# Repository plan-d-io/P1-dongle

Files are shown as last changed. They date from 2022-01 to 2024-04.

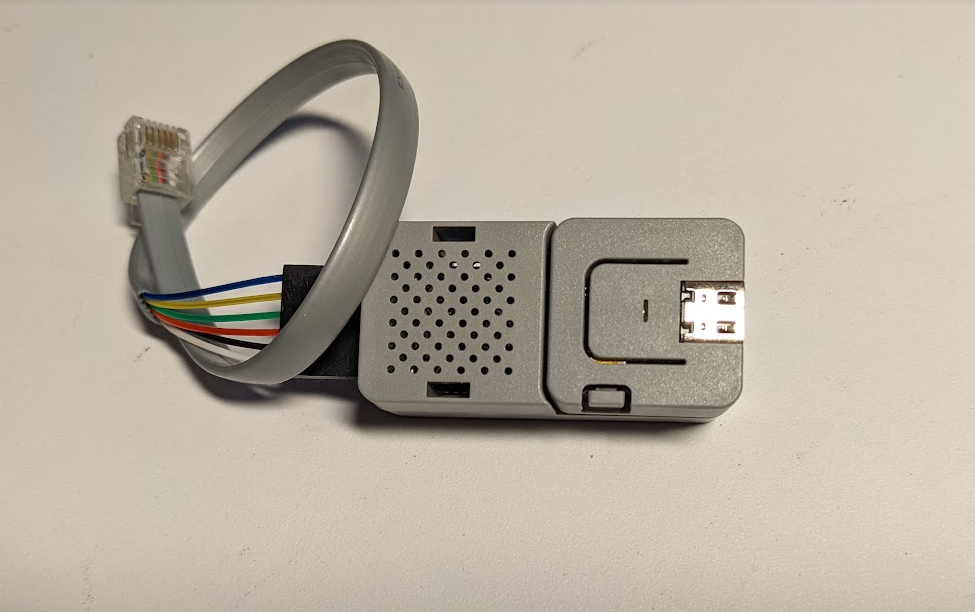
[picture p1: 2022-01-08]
hardware/P1-dongle.PNG

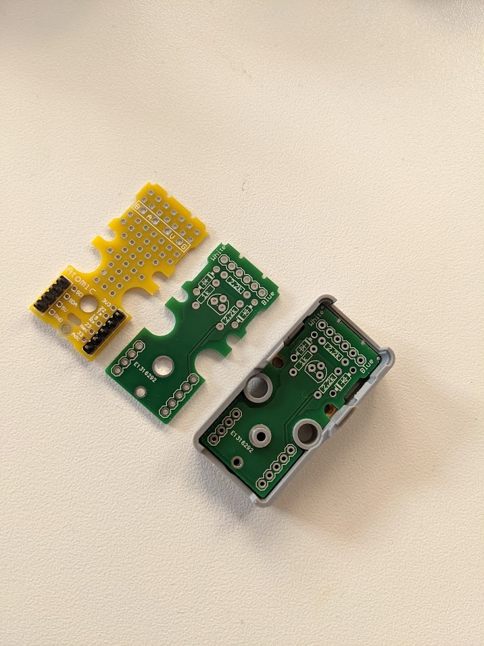
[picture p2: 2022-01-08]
hardware/P1-dongle-PCB.jpg

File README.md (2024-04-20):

# P1-dongle
ESP32-based firmware and hardware to receive, parse, store and forward energy data coming from the P1 port of Fluvius digital meters (Flanders, Belgium). Should also work on Dutch, Walloon, Luxembourg and Swedish digital meters (untested).



Please see the [wiki](https://github.com/plan-d-io/P1-dongle/wiki) for extended instructions on how to build, configure and use the P1-dongle.

## Features
- Professional looking yet easy DIY build
- Cheap (<€20 DIY cost)
- Easy to configure through web-based interface or RESTful API
- Supports MQTT, MQTT over TLS, HTTP and HTTPS data upload to local or remote servers
- Native integration into Home Assistant (MQTT autodiscovery)
- Open source firmware & hardware
- Privacy first: cloud, or even internet access entirely optional
- Auto-updating firmware (optional)
- Easy to use as a basis for other (professional) projects

I do not provide any guarantees nor timelines for developing functionality. I am however available for specific functionality or developments at request. 
And, as this is an open-source project, you are free to contribute yourself!

## Basic installation
1. Plug the P1-dongle into the P1 port of your digital meter
2. When the LED turns greens, connect to the `p1-dongle` access point
3. When connected, open the login page or go to `192.168.4.1`
4. Complete the configuration, and click the reboot button at the bottom of the webpage

# Development
- [Development roadmap](https://github.com/plan-d-io/P1-dongle/wiki/Development:-roadmap)

# Project sponsors
**Elia Innovation**



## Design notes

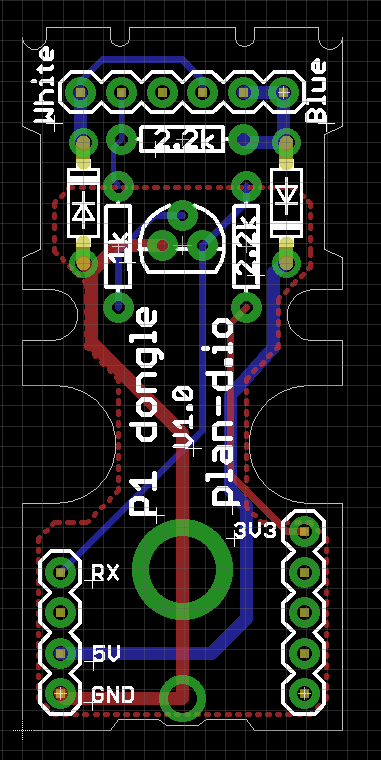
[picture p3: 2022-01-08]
hardware/P1-dongle-eagle.PNG

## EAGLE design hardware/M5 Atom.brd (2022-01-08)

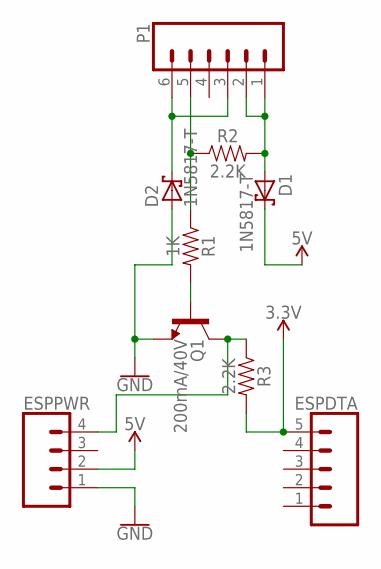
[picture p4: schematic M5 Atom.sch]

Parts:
D1, D2: 1N5817-T; DO41-7.6
ESPDTA: CONN_05; 1X05
ESPPWR: CONN_04PTH; 1X04
P1: CONN_06SILK_FEMALE_PTH; 1X06
Q1: 200mA/40V; TO-92
R1: 1K; AXIAL-0.3
R2, R3: 2.2K; AXIAL-0.3

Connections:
3.3V: ESPDTA.5, R3.P$2 (2)
5V: D1.C, ESPPWR.2
5VH: D1.A, P1.1, P1.2, R2.P$2 (2)
GND: D2.A, ESPPWR.1, Q1.1 (E)
GNDH: D2.C, P1.3, P1.6
unnamed: Q1.2 (B), R1.P$2 (2)
TXH: P1.5, R1.P$1 (1), R2.P$1 (1)
TXL: ESPPWR.4, Q1.3 (C), R3.P$1 (1)

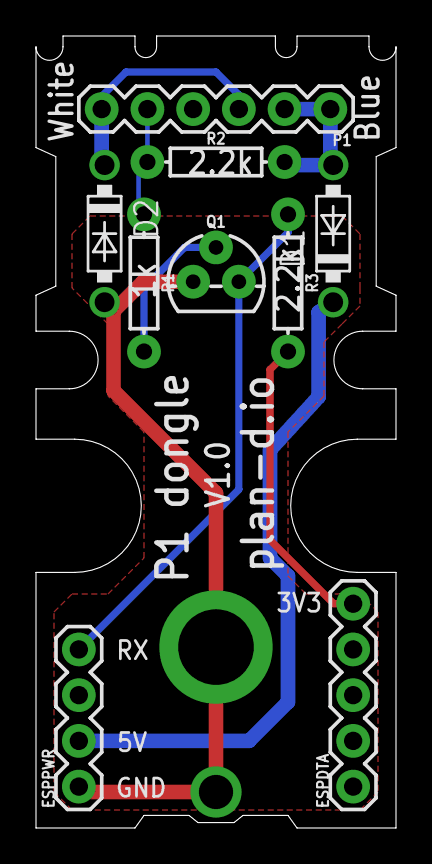
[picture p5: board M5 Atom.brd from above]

Board: 2 copper layers, 20.0 x 44.0 mm, 9 parts (0 on the bottom side), 8 nets.

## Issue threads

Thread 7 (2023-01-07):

Support for WPA2 Enterprise EAP-TTLS

mcuelenaere, 2023-01-07:
I noticed [in the code](https://github.com/plan-d-io/P1-dongle/blob/main/P1-dongle.ino#L180) that currently only WPA/WPA2 Personal support is available.

Having support for WPA2 Enterprise EAP-TTLS would be really useful for certain usecases (read as: [support Telenet Wi-Free](https://www2.telenet.be/nl/klantenservice/wat-is-telenet-wi-free/)).

Based on some quick searching through the ESP32 code, this seems to be [a supported usecase](https://github.com/espressif/arduino-esp32/blob/master/libraries/WiFiClientSecure/examples/WiFiClientSecureEnterprise/WiFiClientSecureEnterprise.ino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) and not too difficult to add support for.

I might look into adding support myself, if I get my hands on a dongle. If not, this issue can be used by someone else as a starting point to implement it.

Epyon01P, 2023-11-20:
I have not identified a clear use case for this, especially now WiF-Free is being shut down. If your digital meter is outside wifi coverage, perhaps you can take a look at my [LoRa dongle](https://github.com/plan-d-io/P1-LoRa-receiver).

Closed 2023-11-20.

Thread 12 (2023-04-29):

Upload to InfluxDB (feature request)

michaelpiron, 2023-04-29:
Feature request:
It would be great if the P1-dongle is able to push measurements directly towards an Influx DB.

Example for inspiration:
IotaWatt energy monitor (ESP-based) is able to upload data to an InfluxDB (version 1 & version 2).
--> https://docs.iotawatt.com/en/master/influxDB.html

UI allows to configure:
* post interval
* bulk send (how many samples are aggregated into one HTTP request)
* server URL
* tags

Code opensource on Github:
* https://github.com/boblemaire/IoTaWatt/blob/master/Firmware/IotaWatt/influxDB_v1_uploader.cpp
* https://github.com/boblemaire/IoTaWatt/blob/master/Firmware/IotaWatt/influxDB_v2_uploader.cpp

Epyon01P, 2023-06-07:
Good suggestion. Currently the dongle has no data buffer, so only a direct push to Influx would be possible. A buffer is on the roadmap, so I'll add this feature afterwards.

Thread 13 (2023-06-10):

add "state_class": "total_increasing", to T1 and T2

koenkv, 2023-06-10:
can you add the "state_class": "total_increasing", to the mqtt message for homeassistant/sensor/utility_meter_total_consumption_t1 and homeassistant/sensor/utility_meter_total_consumption_t2

Epyon01P, 2023-11-23:
Fixed in version 2.10

Closed 2023-11-23.

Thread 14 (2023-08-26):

Discovered entities with a name that starts with the device name

waaslandwolf, 2023-08-26:
Since doing an upgrade, I receive the following warning in Home Assistant for the P1 dongle device:

Discovered entities with a name that starts with the device name

This stops working in version 2024.2.0. Please address before upgrading.

Some MQTT entities have an entity name that starts with the device name. This is not expected. To avoid a duplicate name the device name prefix is stripped off the entity name as a work-a-round. Please inform the maintainer of the software application that supplies the affected entities to fix this issue.

List of affected entities:

    sensor.p197af50_reboots
    sensor.utility_meter_total_consumption_t2
    sensor.p197af50_free_heap_size
    sensor.p197af50_min_free_heap
    sensor.cofyaf50_firmware
    sensor.utility_meter_voltage_phase_2
    sensor.utility_meter_total_consumption_t1
    sensor.cofyaf50_last_reset_reason
    sensor.utility_meter_current_phase_1
    sensor.cofyaf50_syslog
    sensor.utility_meter_active_power_consumption
    sensor.utility_meter_text_message
    sensor.cofyaf50_reboots
    sensor.cofyaf50_min_free_heap
    sensor.utility_meter_maximum_demand_current_month
    sensor.p197af50_ip
    sensor.cofyaf50_free_heap_size
    sensor.utility_meter_total_active_power
    sensor.p197af50_last_reset_reason
    sensor.cofyaf50_max_allocatable_block
    sensor.utility_meter_voltage_phase_1
    sensor.utility_meter_natural_gas_consumption
    sensor.p197af50_max_allocatable_block
    sensor.p197af50_last_reset_reason_verbose
    switch.p197af50_reboot
    sensor.cofyaf50_last_reset_reason_verbose
    sensor.utility_meter_current_average_demand
    sensor.p197af50_syslog
    sensor.utility_meter_total_energy_injected
    sensor.utility_meter_current_phase_3
    sensor.p197af50_firmware
    sensor.utility_meter_total_injection_t2
    sensor.utility_meter_active_power_injection
    sensor.cofyaf50_ip
    sensor.utility_meter_active_tariff_period
    sensor.utility_meter_total_injection_t1
    sensor.utility_meter_current_phase_2
    sensor.utility_meter_voltage_phase_3
    switch.cofyaf50_reboot
    sensor.utility_meter_total_energy_consumed

Home Assistant: Installed version 2023.8.3
P1 Dongle: INFO: Digital meter dongle COFYAF50 V1.08 by plan-d.io

Epyon01P, 2023-11-20:
Fixed with version 2.x

Closed 2023-11-20.

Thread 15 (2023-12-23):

Spiking/dropping sensor values in HA

michaelpiron, 2023-12-23:
Every now and then, sensor values from the P1 dongle have spikes in Home Assistant.

Example: Utility meter Maximum demand current month:
Peak value of over 2.000.000.000 kW:
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

This also happens with sensor Utility meter total energy consumed:
The example below shows a short but deep drop in the normally increasing value, which blows up the whole energy cost calculation:
Drop in total energy consumed:
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

Resulting energy cost calculation:
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

Firmware version 2.10:
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

More debug info:
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

Epyon01P, 2023-12-24:
Coincidentally, I noticed the same behaviour this week too. I have implemented a fix and pushed it to the develop branch. If you switch the release channel (under Dongle setttings in the webmin) you will fetch the latest version (v2.17). Your dongle will reboot multiple times, as I also switched to a new TLS certificate bundle. There is [one breaking change](https://github.com/plan-d-io/P1-dongle/releases/tag/V2.15), but it only concerns the EnergieID integration.

I will push it to the main channel next week.

michaelpiron, 2024-01-09:
I deployed the new version on my dongle, things were running correctly for days, however today I got this:
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

Epyon01P, 2024-01-10:
Implemented test fix in v2.19 on development branch.

michaelpiron, 2024-01-18:
I still have issues:
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

Issue started 15-Jan at noon:
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

Syslog:
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

Epyon01P, 2024-01-20:
Added extra checks in v2.20.

michaelpiron, 2024-01-22:
Issue still present in v2.2.
Today:
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

Epyon01P, 2024-01-22:
Thanks. Seeing how it is now just a erroneous reading and not an overflow anymore gave me more insight in the problem. Test fix pushed to V2.21 on develop.

jantielens, 2024-03-25:
Is this supposed to be fixed in v2.2? I'm still seeing gigantic spikes, for example here in my gas consumption.
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
(I hope these values are incorrect ;) )

Epyon01P, 2024-03-25:
Are you also on develop, or on main?

jantielens, 2024-03-26:
> Are you also on develop, or on main?

I'm on main.

Epyon01P, 2024-04-20:
Should be fixed now in V2.23.

Closed 2024-05-14.

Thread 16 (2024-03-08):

Total active power no longer updated

michaelpiron, 2024-03-08:
Since 20minutes ago, the dongle stopped publishing "total_active_power" values, whereas "active_power_consumption" & "active_power_production" continue to be updated.

MQTT log:
data > devices > utility_meter has no "total_active_power" topic anymore:
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

Sensor "active_power_injection" still being updated:
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

Sensor "total_active_power" stopped being updated:
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

michaelpiron, 2024-03-08:
A few minutes later, the "total_active_power" topic has appeared again in the MQTT log, and the HA sensor is again being updated:
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

There has been a gap for 23 minutes:
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

What could be causing this?

Epyon01P, 2024-03-16:
I believe the spurious reading detection is acting up again. Which release channel are you on? This should be fixed on the develop channel.

michaelpiron, 2024-03-17:
I’m on dev channel, and have been on version 2.22 when the issue happened:

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

jantielens, 2024-03-25:
Same here. For a couple of weeks, the "Total active power" value "gets stuck" randomly, and for some random time.
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

Epyon01P, 2024-03-25:
Thx, very helpful. This is due the way the dongle currently blanks invalid readings received from the meter. I will overhaul the whole function to also fix #15 .

Epyon01P, 2024-04-02:
Pushed a (long overdue) fix to dev. Should also fix #15 .
The issue had to do with negative values (injection) being incorrectly flagged as invalid. This slipped through my testing routine (I don't have solar panels).

Epyon01P, 2024-04-20:
Fixed in V2.23.

maxhelskens, 2024-11-06:
I am not sure if this is the same issue, but I constantly get the following syslog message:

```
WARNING: Spurious value for DSMR key 1-0:2.8.2: 0.01, 2, 1
```

The log is always about key 2.8.2.

Multiple HA entities remain unknown and the other entities do not always update.

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

I have Firmware version 2.23 installed.

Closed 2024-04-20.

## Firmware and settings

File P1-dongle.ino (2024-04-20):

#include "rom/rtc.h"
#include <esp_int_wdt.h>
#include <esp_task_wdt.h>
#include "M5Atom.h"
#include <LittleFS.h>
#define SPIFFS LittleFS
#include <WiFi.h>
#include <HTTPClient.h>
#include <WiFiClientSecure.h>
#include <DNSServer.h>
#include <ESPmDNS.h>
#include <WiFi.h>
#include <AsyncTCP.h>
#include "ESPAsyncWebServer.h"
#include <Preferences.h>
#include <PubSubClient.h>
#include <time.h>
#include <Update.h>
#include "ArduinoJson.h"
#include <elapsedMillis.h>
#include "UUID.h"
#include "configStore.h"
#include "ledControl.h"
#include "externalIntegrations.h"
#include "WebRequestHandler.h"
#include "webHelp.h"
#define HWSERIAL Serial1
#define TRIGGER 25 //Pin to trigger meter telegram request

unsigned int fw_ver = 223;

//General global vars
Preferences preferences;
AsyncWebServer server(80);
DNSServer dnsServer;
uint8_t* certData = nullptr; 
WiFiClient wificlient;
PubSubClient mqttclient(wificlient);
WiFiClientSecure *client = new WiFiClientSecure;
PubSubClient mqttclientSecure(*client);
HTTPClient https;
UUID uuid;
bool clientSecureBusy, mqttPaused, mqttWasPaused, resetWifi, factoryReset, updateAvailable;
bool wifiError, mqttWasConnected, wifiSave, wifiScan, debugInfo, timeconfigured, timeSet, spiffsMounted,rebootInit;
bool bundleLoaded = true;
bool haDiscovered = false;
String configBuffer, resetReason, infoMsg, ssidList;
char apSSID[] = "P1000000";
unsigned int mqttPushCount, mqttPushFails, onlineVersion, fw_new;
unsigned int secureClientError = 0;
time_t meterTimestamp;
//Global timing vars
elapsedMillis sinceConnCheck, sinceUpdateCheck, sinceClockCheck, sinceLastUpload, sinceDebugUpload, sinceRebootCheck, sinceMeterCheck, sinceWifiCheck, sinceTelegramRequest;
//General housekeeping vars
unsigned int reconncount, remotehostcount, telegramCount, telegramAction;
int wifiRSSI;
float freeHeap, minFreeHeap, maxAllocHeap;
byte mac[6];
uint8_t prevButtonState = false;
/*Debug*/
bool serialDebug = true;
bool telegramDebug = false;
bool mqttDebug = false;
bool httpDebug = false;
bool extendedTelegramDebug = false;

void setup(){
  M5.begin(true, false, true);
  delay(2000);
  pinMode(TRIGGER, OUTPUT);
  setBuff(0x00, 0xff, 0x00); //red 
  M5.dis.displaybuff(DisBuff);
  unitState = -1;
  Serial.begin(115200);
  HWSERIAL.begin(115200, SERIAL_8N1, 21, 22);
  delay(500);
  getHostname();
  Serial.println();
  syslog("Digital meter dongle booting", 0);
  restoreConfig();
  initSPIFFS();
  externalIntegrationsBootstrap();
  if(_trigger_type == 0) digitalWrite(TRIGGER, HIGH);
  else digitalWrite(TRIGGER, LOW);
  syslog("Digital meter dongle " + String(apSSID) +" V" + String(fw_ver/100.0) + " by plan-d.io", 1);
  if(_dev_fleet) syslog("Using experimental (development) firmware", 2); //change this to one variable, but keep legacy compatibility intact
  if(_alpha_fleet) syslog("Using pre-release (alpha) firmware", 0);
  if(_v2_fleet) syslog("Using V2.0 firmware", 0);
  syslog("Checking if internal clock is set", 0);
  printLocalTime(true);
  _bootcount = _bootcount + 1;
  syslog("Boot #" + String(_bootcount), 1);
  saveBoots();
  get_reset_reason(rtc_get_reset_reason(0));
  syslog("Last reset reason (hardware): " + resetReason, 1);
  syslog("Last reset reason (firmware): " + _last_reset, 1);
  debugInfo = true;
  initWifi();
  server.addHandler(new WebRequestHandler());
  server.begin();
  configBuffer = returnConfig();
  String availabilityTopic = _mqtt_prefix.substring(0, _mqtt_prefix.length()-1);
  Serial.println("Done");
}

void loop(){
  blinkLed();
  if(wifiScan) scanWifi();
  if(sinceRebootCheck > 2000){
    if(rebootInit){
      forcedReset();
    }
    sinceRebootCheck = 0;
  }
  if(_trigger_type == 0){
    /*Continous triggering of meter telegrams*/
    if(sinceMeterCheck > 30000){
      if(!meterError) syslog("Meter disconnected", 2);
      meterError = true;
      if(_wifi_STA && unitState < 7) unitState = 6;
      else if(!_wifi_STA && unitState < 3) unitState = 2;
      sinceMeterCheck = 0;
    }
  }
  else if(_trigger_type == 1){
    /*On demand triggering of meter telegram*/
    if(sinceTelegramRequest >= _trigger_interval *1000){
      digitalWrite(TRIGGER, HIGH);
      sinceTelegramRequest = 0;
    }
    if(sinceMeterCheck > (_trigger_interval *1000) + 30000){
      syslog("Meter disconnected", 2);
      meterError = true;
      if(_wifi_STA && unitState < 7) unitState = 6;
      else if(!_wifi_STA && unitState < 3) unitState = 2;
      sinceMeterCheck = 0;
    }
  }
  if(!_wifi_STA){
    /*If dongle is in access point mode*/
    dnsServer.processNextRequest();
    if(sinceWifiCheck >= 600000){
      /*If dongle is in AP mode, check every once in a while if the configured wifi SSID can't be detected
       * If so, reboot so the dongle starts up again in connected STA mode. */
      if(scanWifi()){
        saveResetReason("Found saved WiFi SSID, rebooting to reconnect");
        if(saveConfig()){
          syslog("Found saved WiFi SSID, rebooting to reconnect", 1);
          setReboot();
        }
      }
      sinceWifiCheck = 0;
    }
    if(sinceClockCheck >= 600000){
      timeSet = false;
      sinceClockCheck = 0;
    }
  }
  else{
    /*If dongle is connected to wifi*/
    if(!bundleLoaded) restoreSPIFFS();
    if(_mqtt_en){
      if(_mqtt_tls){
        mqttclientSecure.loop();
      }
      else{
        mqttclient.loop();
      }
    }
    if(lastEIDcheck >= EIDcheckInterval){
      eidHello();
    }
    if(lastEIDupload > EIDuploadInterval){
      eidUpload();
    }
    if(_update_autoCheck && sinceUpdateCheck >= 86400000){
      updateAvailable = checkUpdate();
      if(updateAvailable) startUpdate();
      sinceUpdateCheck = 0;
    }
    if(sinceClockCheck >= 3600){
      if(!timeconfigured) timeSet = false; //if timeConfigured = true, the NTP serivce takes care of reqular clock syncing
      sinceClockCheck = 0;
    }
    if(sinceConnCheck >= 60000){
      if(_ha_en && debugInfo) hadebugDevice(false);
      checkConnection();
      sinceConnCheck = 0;
    }
    if(sinceDebugUpload >= 300000){
      getHeapDebug();
      sinceDebugUpload = 0;
    }
    /*If no remote hosts can be reached anymore, try a reboot for up to four times*/
    if(reconncount > 15 || remotehostcount > 60 || secureClientError > 4){
      _rebootSecure++;
      if(_rebootSecure < 4){
        saveResetReason("Rebooting to try fix connections");
        if(saveConfig()){
          syslog("Rebooting to try fix connections", 2);
          setReboot();
        }
        reconncount = 0;
      }
      else{
        /*After four reboots, increase time between reboots drastically*/
        if(reconncount > 150 || remotehostcount > 600 || secureClientError > 40){
          _rebootSecure++;
          saveResetReason("Rebooting to try fix connections");
          if(saveConfig()){
            syslog("Rebooting to try fix connections", 2);
            setReboot();
          }
          reconncount = 0;
        }
      }
    }
  }
  M5.update();
  if (M5.Btn.pressedFor(2000)) {
    resetWifi = true;
  }
  if (M5.Btn.pressedFor(5000)) {
    resetWifi = false;
    factoryReset = true;
  }
  if (prevButtonState != M5.Btn.isPressed()) {
    if(!M5.Btn.isPressed()){
      if(factoryReset || resetWifi){
        resetConfig();
      }
    }
  }
  prevButtonState = M5.Btn.isPressed();
  if(HWSERIAL.available() > 0) {
    /*Read the received meter telegram. A telegram ends on the '!' character, followed by a 4-digit CRC16 value*/
    String telegram=HWSERIAL.readStringUntil('!');
    telegram = telegram + '\n';
    String crc =  HWSERIAL.readStringUntil('\n');
    if(_trigger_type == 1){
      digitalWrite(TRIGGER, LOW);
      sinceTelegramRequest = 0;
    }
    processMeterTelegram(telegram, crc);
  }
}

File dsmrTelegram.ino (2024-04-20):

/*Configure and process the meter telegram*/

struct mbusMeterType {
      String mbusKey;
      int type = 0; //3 = gas meter, 4 = heat/cold, 7 = water meter
      int measurementType = 0; //1 = base value, 3 = non-temperature compensated
      String id;
      float keyValueFloat;
      unsigned long keyTimeStamp;
      bool enabled;
      bool keyFound;
};
mbusMeterType mbusMeter[4];

struct keyConfig {
  String dsmrKey;
  float* keyValueFloat;
  unsigned long* keyValueLong;
  String* keyValueString;
  uint8_t keyType;
  String deviceType;
  String  keyName;
  String  keyTopic;
  bool retain;
  bool* keyFound;
};

struct mbusConfig {
  int keyType; //3 = gas meter, 4 = heat/cold, 7 = water meter
  String deviceType;
  String  keyName;
  String  keyTopic;
  bool retain;
};

float dummyFloat, totConT1, totConT2, totCon, totInT1, totInT2, totIn, powCon, powIn, netPowCon, totGasCon, totWatCon, totHeatCon, volt1, volt2, volt3, current1, current2, current3, avgDem, maxDemM;
float prevtotConT1, prevtotConT2, prevtotCon, prevtotIntT1, prevtotIntT2, prevtotIn;
unsigned long dummyInt, actTarrif, maxDemTime, totGasTime, totWatTime, totHeatTime;
String dummyString, p1Version, meterId;
bool dummyBool, totConFound, totInFound, netPowConFound, totConT1Found, totConT2Found, totInT1Found, totInT2Found, actTarrifFound, powConFound, powInFound, avgDemFound, maxDemMFound, volt1Found, current1Found, volt2Found, volt3Found, current2Found, current3Found;
int spurCount;

static const keyConfig dsmrKeys[] PROGMEM = {
  /*The list of all possible DSMR keys and how to parse them.
   * { "DSMR key code", key type, "HA device type", "user-readable name", "mqtt topic", retain, key found in telegram }
   * Key types:
   *  0: other
   *  1: numeric (floating point) without unit, e.g. 0-0:96.14.0(0002)
   *  2: numeric (floating point) with unit, e.g. 1-0:1.4.0(02.351*kW)
   *  3: timestamped (Mbus) message, e.g. 0-1:24.2.3(200512134558S)(00112.384*m3)
   *  4: string, e.g. 0-0:96.13.0(3031323334353)
   *  5: integer
   *  The key type determines how the associated value will be parsed.
   * Home Assistant device types: see https://developers.home-assistant.io/docs/core/entity/sensor/#available-device-classes
   *  Examples: "" (none), power, energy, voltage, current, natural gas, water, heat.
   *  The device type determines how the value will be registered and represented in Home Assistant. You can leave this to "" (none) if you don't use HA.
   * Mqtt topic:
   *  The MQTT topic to post the measurement to. Will be prefixed by mqtt_prefix (standard: data/devices/utility_meter/).
   *  If left empty, the firmware will use the user readable name cast to lowercase with spaces replaced by _
   * Retain:
   *  If the MQTT payload should be sent with the retain flag.
   * IMPORTANT
   *  DSMR keys are adressed in the firmware by their order in this array. DO NOT rearrange keys.
   *  If you want to add new keys, add them to the bottom of the array.
   */
    /*The first three keys are custom keys, required for dongle operation*/
    { "A-0:0.0.1", &totCon, &dummyInt, &dummyString, 2, "energy", "Total energy consumed",  "",  false, &totConFound},
    { "A-0:0.0.2", &totIn, &dummyInt, &dummyString, 2, "energy", "Total energy injected",  "",  false, &totInFound},
    { "A-0:0.0.3", &netPowCon, &dummyInt, &dummyString, 2, "power", "Total active power",  "",  false, &netPowConFound},
    /*Standard keys (required)*/
    { "1-0:1.8.1", &totConT1, &dummyInt, &dummyString, 2, "energy", "Total consumption T1",  "",  false, &totConT1Found},
    { "1-0:1.8.2", &totConT2, &dummyInt, &dummyString, 2, "energy", "Total consumption T2",  "",  false, &totConT2Found},
    { "1-0:2.8.1", &totInT1, &dummyInt, &dummyString, 2, "energy", "Total injection T1",  "",  false, &totInT1Found},
    { "1-0:2.8.2", &totInT2, &dummyInt, &dummyString, 2, "energy", "Total injection T2",  "",  false, &totInT2Found},
    { "0-0:96.14.0", &dummyFloat, &actTarrif, &dummyString, 5, "", "Active tariff period",  "",  false, &actTarrifFound},
    { "1-0:1.7.0", &powCon, &dummyInt, &dummyString, 2, "power", "Active power consumption",  "",  false, &powConFound},
    { "1-0:2.7.0", &powIn, &dummyInt, &dummyString, 2, "power", "Active power injection",  "",  false, &powInFound},
    { "1-0:1.4.0", &avgDem, &dummyInt, &dummyString, 2,"power", "Current average demand",  "",  false, &avgDemFound},
    { "1-0:1.6.0", &maxDemM, &maxDemTime, &dummyString, 3, "power", "Maximum demand current month",  "",  false, &maxDemMFound},
    { "1-0:32.7.0", &volt1, &dummyInt, &dummyString, 2, "voltage", "Voltage phase 1", "",  false, &volt1Found},
    { "1-0:31.7.0", &current1, &dummyInt, &dummyString, 2, "current", "Current phase 1", "",  false, &current1Found},
    /*Custom keys, add your own here (optional)*/
    { "1-0:52.7.0", &volt2, &dummyInt, &dummyString, 2, "voltage", "Voltage phase 2", "",  false, &volt2Found},
    { "1-0:72.7.0", &volt3, &dummyInt, &dummyString, 2, "voltage", "Voltage phase 3", "",  false, &volt3Found},
    { "1-0:51.7.0", &current2, &dummyInt, &dummyString, 2, "current", "Current phase 2", "",  false, &current2Found},
    { "1-0:71.7.0", &current3, &dummyInt, &dummyString, 2, "current", "Current phase 3", "",  false, &current3Found}
    //{ "0-0:96.13.0", &dummyFloat, &dummyInt, &dummyString, 4, "", "Text message", "",  false, &dummyBool}
};

float gasValue, heatValue, waterValue;
unsigned long gasTime, heatTime, waterTime;
static const mbusConfig mbusKeys[] PROGMEM = {
  /*The availability and id of M-bus meters (water, gas, heat, ...) is dependent on your type of installation, so you can't set the Mbus OBIS keys to be extracted
   * from the telegram beforehand.
   * The dongle will automatically detect the type and id of connected M-bus meter and process the data according to the fields in this list (e.g. MQTT topic).
   * If the M-bus meter reports both temperature (base) and non-temperature corrected values, the temperature corrected value will be used.
   * If you want to extract a specific M-bus key, add it to the dsmrKeys list above.
   * Format: { Mbus meter type, HA device type, "user-readable name", "mqtt topic", retain }
   * Mqtt topic: see note in dsmrKeys above
   * Mbus meter types:
   *  3: natural gas
   *  4: heat/cold
   *  7: water
   * Note: multiple M-bus meters from the same type are currently not supported
   */
    { 3, "gas", "Natural gas consumption", "",  false},
    { 4, "", "heat", "",  false},
    { 7, "water", "Water consumption", "",  false}
};
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

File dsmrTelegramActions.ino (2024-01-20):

/*Add your custom functions to process meter readings here*/

void onTelegram(){
  /*This function is executed whenever a meter telegram containing a meterID and meterTimestamp is received.
   * Use this function if you want the most recent meter updates
   */
  //printTelegramValues();
  controlHA();
  mqttPushTelegramValues();
}

void onTelegramCrc(){
  /*This function is executed whenever a meter telegram containing a meterID, a meterTimestamp and a valid CRC is received.
   * Sometimes a meter telegram containing valid measurements can be reveived, but the CRC can be off.
   * Use this function if you want absolute assurance about the telegram contents.
   */
}

void printTelegramValues(){
  /*Example function which loops over both the configured DSMR keys and the detected Mbus keys and, if found, prints their value.
   * This function shows you how you can access these keys and their values.
   */
  Serial.print("Meter ID: ");
  Serial.println(meterId);
  Serial.print("Meter time: ");
  Serial.print(meterTimestamp);
  Serial.print(" ");
  struct tm meterTime;
  localtime_r(&meterTimestamp , &meterTime);
  char timeStringBuff[30];
  strftime(timeStringBuff,sizeof(timeStringBuff),"%A, %B %d %Y %H:%M:%S", &meterTime);
  Serial.println(timeStringBuff);
  /*Loop over the configured DSMR keys and, if present in the received meter telegram, print them*/ 
  for(int i = 0; i < sizeof(dsmrKeys)/sizeof(dsmrKeys[0]); i++){
    if(*dsmrKeys[i].keyFound == true){
      Serial.print(dsmrKeys[i].keyName);
      Serial.print(": ");
      if(dsmrKeys[i].keyType > 0 && dsmrKeys[i].keyType < 4){
        if(fmodf(*dsmrKeys[i].keyValueFloat, 1.0) == 0) Serial.print(int(*dsmrKeys[i].keyValueFloat));
        else Serial.print(round2(*dsmrKeys[i].keyValueFloat));
        Serial.print(" ");
      }
      if(dsmrKeys[i].keyType == 2 || dsmrKeys[i].keyType == 3){
        if(dsmrKeys[i].deviceType == "energy") Serial.print("kWh ");
        else if(dsmrKeys[i].deviceType == "power") Serial.print("kW ");
        else if(dsmrKeys[i].deviceType == "power") Serial.print("kW ");
        else if(dsmrKeys[i].deviceType == "voltage") Serial.print("V ");
        else if(dsmrKeys[i].deviceType == "current") Serial.print("A ");
        else Serial.print(" ");
      }
      if(dsmrKeys[i].keyType == 3){
        Serial.print("(");
        Serial.print(*dsmrKeys[i].keyValueLong);
        Serial.print(")");
      }
      if(dsmrKeys[i].keyType == 4){
        Serial.print(*dsmrKeys[i].keyValueString);
      }
      if(dsmrKeys[i].keyType == 5){
        Serial.print(*dsmrKeys[i].keyValueLong);
      }
      Serial.println("");
    }
  }
  /*Loop over the Mbus keys found in the meter telegram and print their value*/
  for(int i = 0; i < sizeof(mbusMeter)/sizeof(mbusMeter[0]); i++){
    if(mbusMeter[i].keyFound == true){
      if(mbusMeter[i].type == 3) Serial.print("Natural gas consumption: ");
      else if (mbusMeter[i].type == 4) Serial.print("Heat consumption: ");
      else if (mbusMeter[i].type == 7) Serial.print("Water consumption: ");
      if(fmodf(mbusMeter[i].keyValueFloat, 1.0) == 0) Serial.print(int(mbusMeter[i].keyValueFloat));
      else Serial.print(round2(mbusMeter[i].keyValueFloat));
      if(mbusMeter[i].type == 3 || mbusMeter[i].type == 7) Serial.print(" m³ (");
      else if (mbusMeter[i].type == 7) Serial.print(" kWh (");
      Serial.print(mbusMeter[i].keyTimeStamp);
      Serial.println(")");
    }
  }
}

void mqttPushTelegramValues(){
  if(_mqtt_en){
    if(sinceLastUpload > _upload_throttle*1000){
      Serial.println(ESP.getFreeHeap()/1000.0);
      if(mqttDebug) Serial.println("Performing MQTT push");
      String availabilityTopic = _mqtt_prefix.substring(0, _mqtt_prefix.length()-1);
      pubMqtt(availabilityTopic, "online", false);
      /*Loop over the configured DSMR keys and, if found in the meter telegram and enabled, push their value over MQTT*/
      for(int i = 0; i < sizeof(dsmrKeys)/sizeof(dsmrKeys[0]); i++){
        if(*dsmrKeys[i].keyFound == true){
          /*Check if the key,value pair needs to be pushed
           * The unsigned long _key_pushlist contains 32 bits indicating if the value needs to be pushed (1) or not (0)
           * E.g. if _key_pushlist is 329, its binary representation is 00000000000000000000000101001001
           * The LSB (at the rightmost side) represents dsmrKeys[0], the bit to the left of it dsmrKeys[1] etc.
           * We boolean AND the _key_pushlist with a binary mask 1, which is shifted to the left according to which key in dsmrKeys[] we are comparing
           * If the result is 1, this means the key,value pair must be pushed
           * E.g. if _key_pushlist is 329, dsmrKeys[0] must be pushed, dsmrKeys[1] not, dsmrKeys[2] not, dsmrKeys[3] must, etc.
           * Sounds complicated, but this way we only need one variable in NVS to store up to 32 options.
           */
          unsigned long mask = 1;
          mask <<= i;
          unsigned long test = _key_pushlist & mask;
          if(test > 0){
            if(mqttDebug){
              Serial.print(dsmrKeys[i].keyName);
              Serial.print(" ");
              Serial.println(dsmrKeyPayload(i));
            }
            pushDSMRKey(dsmrKeys[i].keyName, dsmrKeyPayload(i), "");
          }
        }
      }
      /*Loop over the Mbus keys found in the meter telegram and push their value over MQTT*/
      for(int i = 0; i < sizeof(mbusMeter)/sizeof(mbusMeter[0]); i++){
        String friendlyName;
        if(mbusMeter[i].keyFound == true && mbusMeter[i].enabled == true){
          String tempJson = mbusKeyPayload(i);
          for(int j = 0; j < sizeof(mbusKeys)/sizeof(mbusKeys[0]); j++){
            if(mbusKeys[j].keyType == mbusMeter[i].type){
              friendlyName = mbusKeys[j].keyName;
            }
          }
          if(mqttDebug){
            Serial.print(friendlyName);
            Serial.print(" ");
            Serial.println(tempJson);
          }
          pushDSMRKey(friendlyName, tempJson, "");
        }
      }
      sinceLastUpload = 0;
    }
  }
}
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

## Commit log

2022-03-21 Add auto-reconnect, fix sensorIds
    When in AP mode, dongle will now check if the stored SSID is back up and then reconnect. Fixes situations where, after power outage, dongle reboots before wifi router does.
2022-12-27 Various bugfixes and improvements
    [P1-dongle.ino, configuration.ino, dsmrTelegram.ino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]
2022-12-27 Fix digital meter data point fields
    [P1-dongle.ino, configuration.ino, dsmrTelegram.ino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]
2022-12-28 Improve MQTT user feedback flow
2022-12-28 Improve HA MQTT discovery, remove entities from HA before reboot
    [P1-dongle.ino, mqtt.ino, utilities.ino]
2023-03-12 Fix flash formatting/nvs loss issues
    [P1-dongle.ino, configuration.ino]
2023-04-14 Try to fix upgrade
    [P1-dongle.ino, upgrade.ino]
2023-04-14 Add temp to fix upgrade
    [upgrade.ino]
2023-04-28 Add SPIFFS format fix
    [P1-dongle.ino, configuration.ino, restore.ino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]
2023-07-27 SPIFFS fix, LED behaviour
    [P1-dongle.ino, configuration.ino, mqtt.ino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]
2023-07-29 Fix upload throttle
2023-11-21 Fix EID UUID generation
    [configuration.ino]
2023-11-23 Add smart reboot for connection issues
    [P1-dongle.ino, externalIntegrationsActions.ino, mqtt.ino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]
2023-12-03 Fix factory reset by manually deleting config entries
    [P1-dongle.ino, configuration.ino]
2023-12-03 Fix telegram request line not asserted by default
    [P1-dongle.ino, configuration.ino]
2023-12-04 Add partitions file
    [partitions.csv]
2023-12-13 Change EID deviceName and claimCode
2023-12-13 Fix EID daily interval setting
    [externalIntegrationsActions.ino]
2023-12-17 Try fix EID gas/water/heat uploads
    [P1-dongle.ino, dsmrTelegram.ino, externalIntegrationsActions.ino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]
2023-12-19 Prepare TLS switch
2023-12-24 Add filter for spurious meter readings
2024-01-03 Close and clean up SSL socket after uploading to EID
2024-01-18 Fix reboot over MQTT
    [homeAssistant.ino, mqtt.ino]
2024-04-01 Fix negative values (injection) being discarded as spurious reading
    [P1-dongle.ino, dsmrTelegram.ino]

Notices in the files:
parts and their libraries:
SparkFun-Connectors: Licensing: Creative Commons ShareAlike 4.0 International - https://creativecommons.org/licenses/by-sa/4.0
